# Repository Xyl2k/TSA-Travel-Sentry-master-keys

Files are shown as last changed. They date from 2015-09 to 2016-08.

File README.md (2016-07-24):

tsa

3D TSA "Travel Sentry" master keys
=========
Recently, pictures of TSA master baggage keys got leaked by the Washington Post and also [PDFs](https://www.travelsentry.org/security/pdf/passkeys.pdf) hosted on TravelSentry's Website. This repo is a [reproduction attempt](https://twitter.com/InfoSecJesus/status/641662669758574593) 

Security researchers have [long warned](http://www.crypto.com/masterkey.html) of the dangers of using [master-keyed locks](https://twitter.com/J0hnnyXm4s/status/642123709311008768)

The TSA has issued an official statement making it known that [they don't even care that we've done this](https://theintercept.com/2015/09/16/tsa-doesnt-really-care-luggage-locks-hacked/), as the now-pointless locks affect theft prevention, not airline safety. 

> **[!] Important**: These keys have not been widely-tested, though we do have reports that many [do work](https://twitter.com/bernard/status/641662069427847168) from at least [one source](http://arstechnica.com/security/2015/09/video-3d-printed-tsa-travel-sentry-keys-really-do-open-tsa-locks/). 006 May never work, as we're not sure of the depth of the "dimples," and also consumer-grade 3D printers may not be up to such finely-detailed tasks.

> Added the stubby versions of the keys by [MS3FGX](https://github.com/MS3FGX), which appear to [still work fine !](https://twitter.com/JimyLongs/status/641820527892414464)

### Thanks:
- Special thanks to [@darksim905](https://twitter.com/darksim905) and [@irongeek_adc](https://twitter.com/irongeek_adc/status/640907196197404672) and some anonymous others who all sent us images and information surrounding these keys. Also, [@j0hnnyXm4s](https://twitter.com/J0hnnyXm4s) for his key size ratios and issue management / advice.

3D TSA "Safe Skies" master key
=========
Safe Skies manufactures TSA-approved locks under their own standard, competing with Travel Sentry, and has even sued Travel Sentry for patent infringement. They have a much smaller market share than Travel Sentry. These locks can be identified by noting the words "Safe Skies" next to the keyway, in a similar location as the Travel Sentry "TSA00N" notations. All available information indicates only one override/master key exists for their entire system. Armed with this knowledge and a large hammer (no, really), [@darksim905](https://twitter.com/darksim905) and [Nite0wl](https://twitter.com/nite0wl_2600) reverse-engineered the master key bitting, and created 3D files suitable for printing. They presented their findings along with [@j0hnnyXm4s](https://twitter.com/J0hnnyXm4s) at the 11th Hackers of Planet Earth conference in New York City, in July of 2016.

PROBLEM REPORTING
=========

If you print a key and it doesn't work:
	
* First, use a caliper or other highly-accurate device to make sure the key you printed is accurate to the model. Humidity, expansion & ambient room temperature can have serious effects on print size accuracy.

* If it IS accurate, open an issue on the github, specify the problem file, and what problems exist (i.e. "Too wide for the keyway," "Too tall for the keyway," etc.).

* Upload a picture of your lock's keyway. 

* If you have the original keys for the lock, provide a measurement of the key from shoulder to tip, total height of the shoulders, and width. (i.e. X, Y & Z axes of the blade). Some keys only have one shoulder. 

LICENSE
=========
This project is released under the Creative Commons Attribution-NonCommercial 3.0 Unported License.



You are free to:

* Share — copy and redistribute the material in any medium or format
* Adapt — remix, transform, and build upon the material
* The licensor cannot revoke these freedoms as long as you follow the license terms.

Under the following terms:

* [!]Attribution — You must give appropriate credit to all contributors to this project, provide a link to the license, and indicate if changes were made. You may do so in any reasonable manner, but not in any way that suggests the licensor endorses you or your use.

* [!]NonCommercial — You may not use the material for commercial purposes.
No additional restrictions — You may not apply legal terms or technological measures that legally restrict others from doing anything the license permits.

Notices:

You do not have to comply with the license for elements of the material in the public domain or where your use is permitted by an applicable exception or limitation.

No warranties are given.

For the full text of this license, see [LICENSE.md](https://github.com/Xyl2k/TSA-Travel-Sentry-master-keys/blob/master/LICENSE.md).

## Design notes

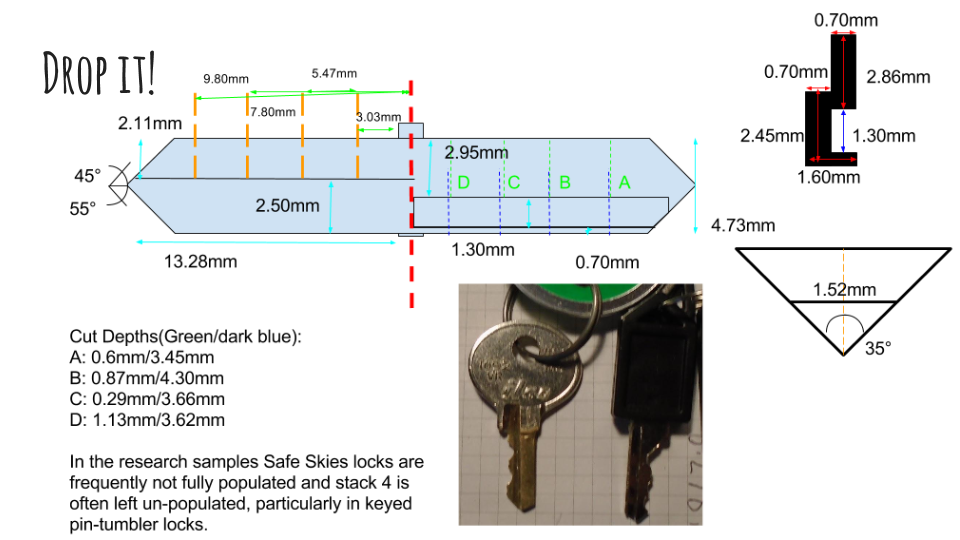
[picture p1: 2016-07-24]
Safe_Skies/Cut__depths__and__angles.png

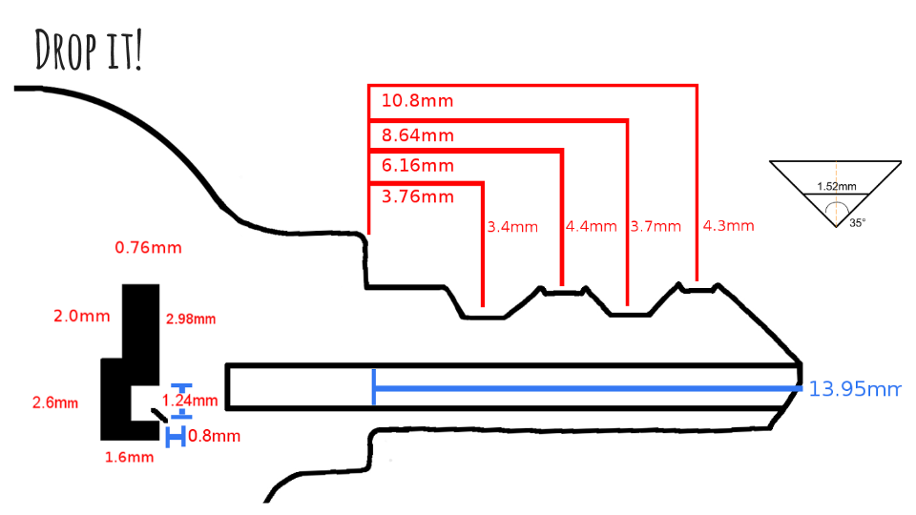
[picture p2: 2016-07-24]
Safe_Skies/Keyway__and__bitting.png

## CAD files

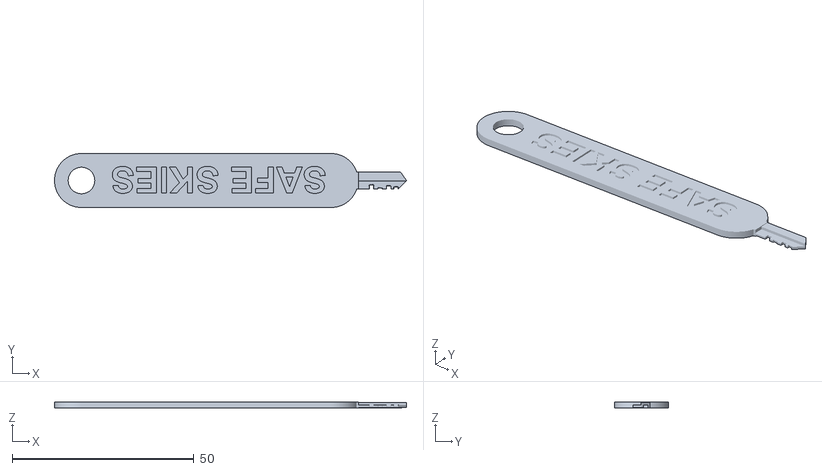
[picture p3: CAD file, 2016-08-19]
Safe_Skies/SafeSkies_full.stl
96.8 x 14.8 x 1.76

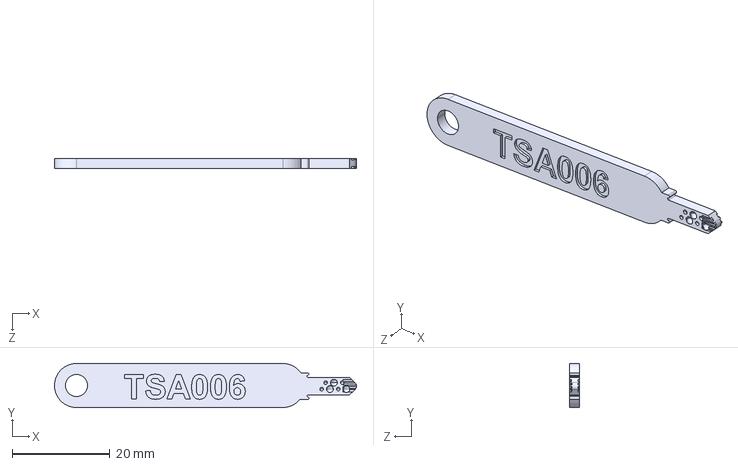
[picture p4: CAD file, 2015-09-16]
IGES/TSA006.IGS
61.7 x 9.00 x 2.00 mm

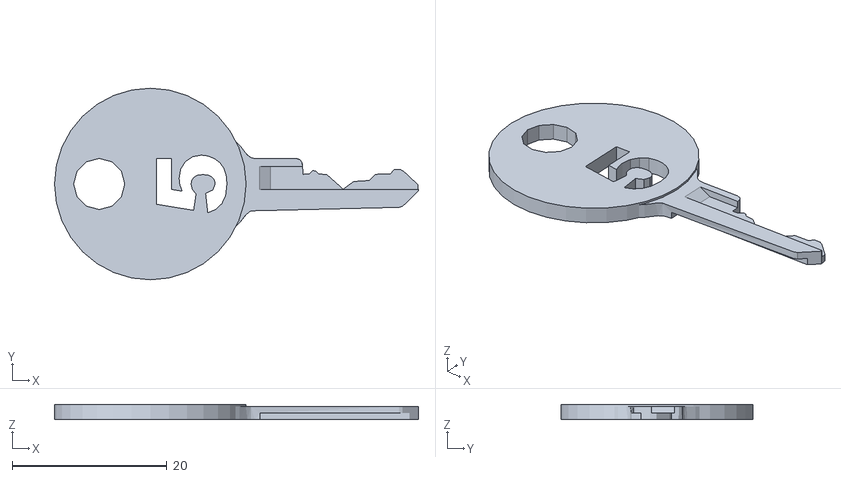
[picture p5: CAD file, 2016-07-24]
TSA005_stubby.stl
47.0 x 24.8 x 1.98

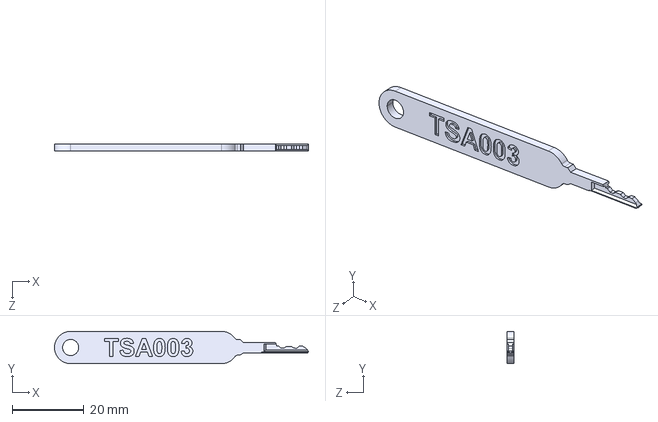
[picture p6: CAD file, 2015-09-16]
IGES/TSA003.IGS
70.9 x 9.00 x 2.00 mm

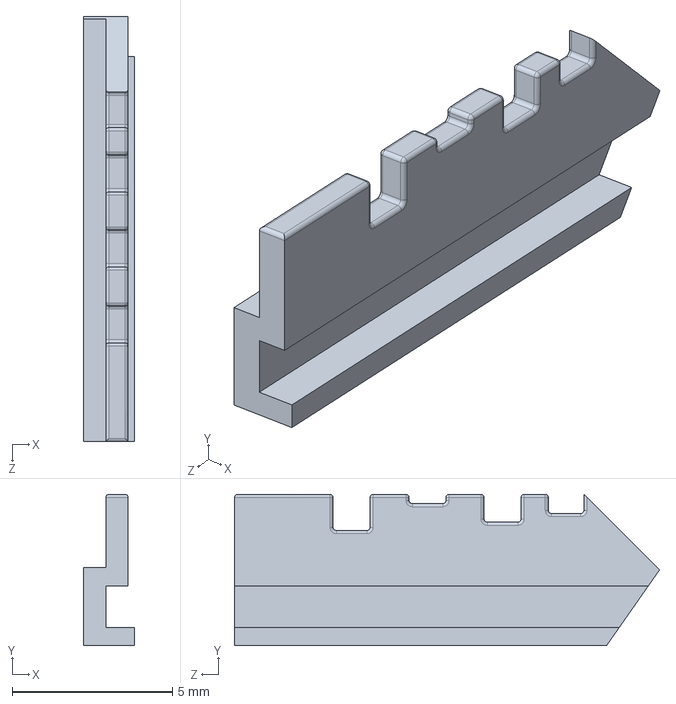
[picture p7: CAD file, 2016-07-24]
Safe_Skies/SafeSkies__FILLET__.SLDPRT
1.60 x 4.73 x 13.3 mm

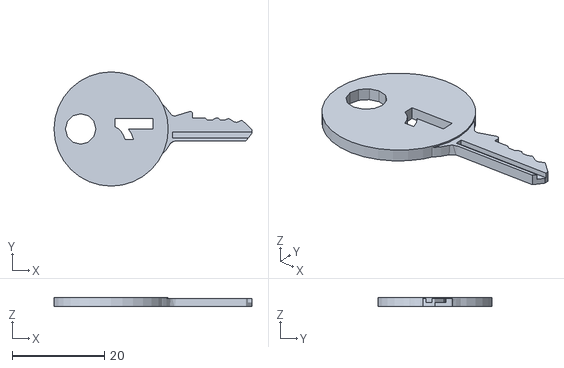
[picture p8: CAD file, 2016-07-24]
TSA001_stubby.stl
42.9 x 24.8 x 2.01

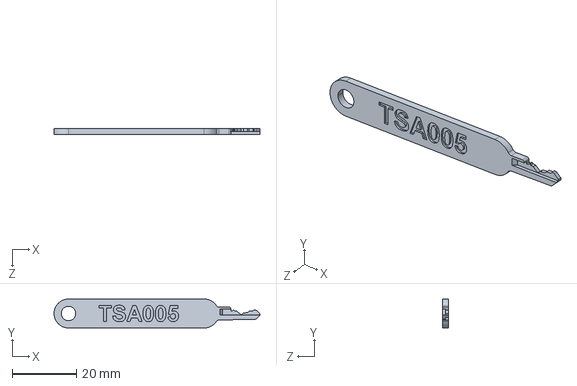
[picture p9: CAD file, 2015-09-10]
IGES/TSA005.IGS
64.0 x 9.00 x 1.75 mm

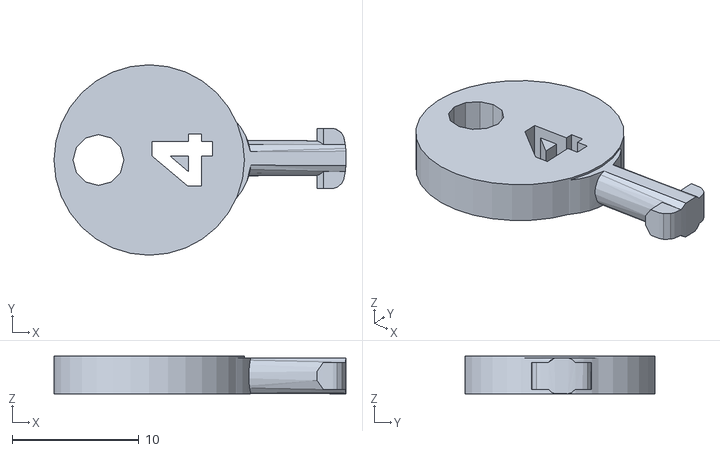
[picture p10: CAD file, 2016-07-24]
TSA004_stubby.stl
23.0 x 15.0 x 2.98

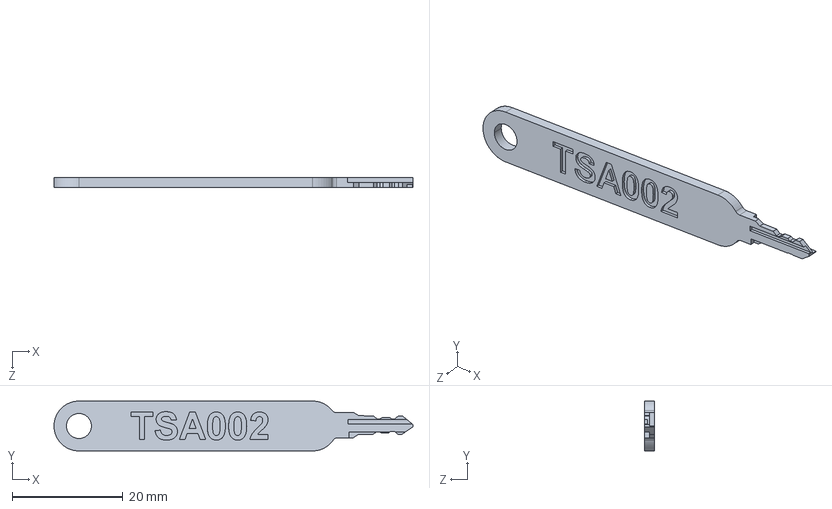
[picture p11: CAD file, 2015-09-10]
IGES/TSA002.IGS
64.7 x 9.00 x 1.75 mm

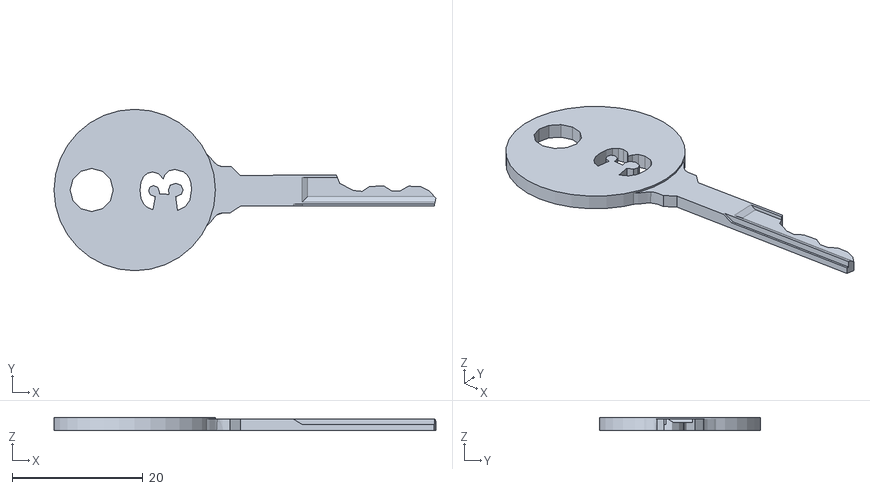
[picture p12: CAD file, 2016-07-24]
TSA003_stubby.stl
58.5 x 24.7 x 2.01

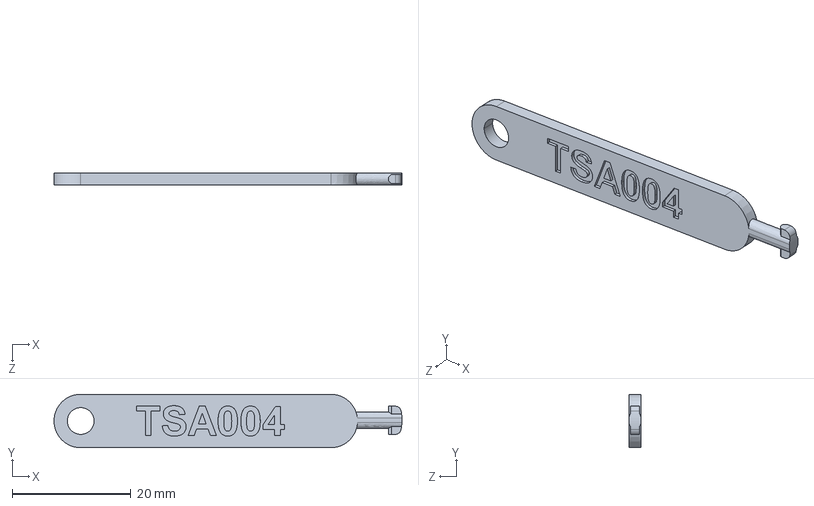
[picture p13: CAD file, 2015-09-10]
IGES/TSA004.IGS
58.6 x 9.00 x 2.00 mm

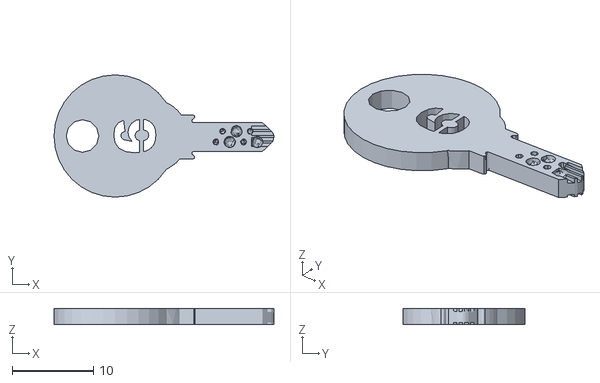
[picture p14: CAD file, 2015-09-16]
TSA006_stubby.stl
27.0 x 15.0 x 2.00

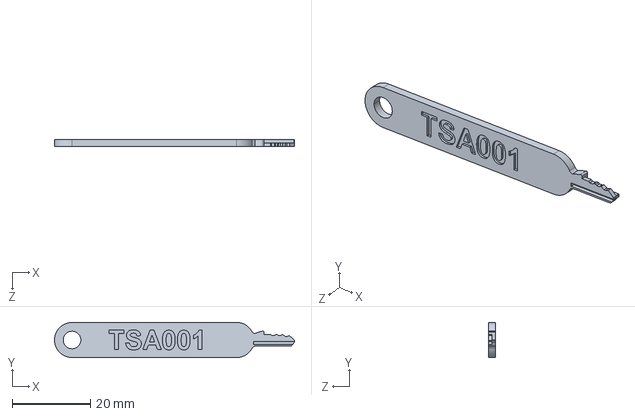
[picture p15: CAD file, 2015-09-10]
IGES/TSA001.IGS
61.5 x 9.00 x 1.75 mm

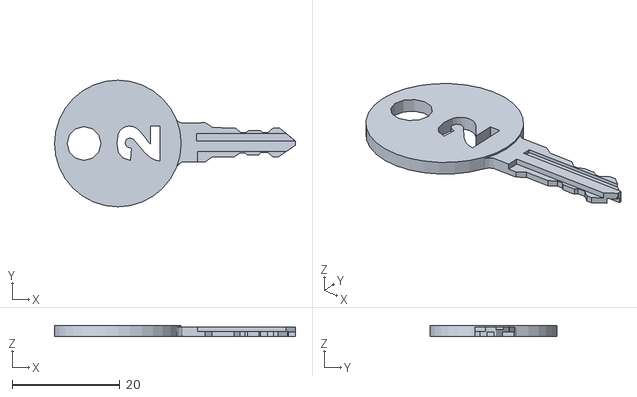
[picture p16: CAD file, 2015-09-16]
TSA002_stubby.stl
44.8 x 23.6 x 2.01

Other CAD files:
Safe_Skies/SafeSkies__no__cuts.SLDPRT
Safe_Skies/SafeSkies.SLDPRT
IGES/TSA007.IGS
TSA007_stubby.stl
Safe_Skies/SafeSkies.stl
TSA001.stl
TSA002.stl
TSA003.stl
TSA004.stl
TSA005.stl
TSA006.stl
TSA007.stl

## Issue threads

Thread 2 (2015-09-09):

Which unit was used?

hanneshal, 2015-09-09:
Which unit was used to create your stl files?
Are they in inch, mm, cm?

regards

Xyl2k, 2015-09-09:
Hi, millimeters

Date: Wed, 9 Sep 2015 10:40:37 -0700
From: notifications@github.com
To: TSA-Travel-Sentry-master-keys@noreply.github.com
Subject: [TSA-Travel-Sentry-master-keys] Which unit was used? (#2)

Which unit was used to create your stl files?

Are they in inch, mm, cm?

regards

—
Reply to this email directly or view it on GitHub.

hanneshal, 2015-09-09:
thx

Closed 2015-09-09.

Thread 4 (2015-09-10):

where's the license?

burdickjp, 2015-09-10:
May I suggest you use the CERN open hardware license?
http://www.ohwr.org/documents/294

3TroubleMonster, 2015-09-10:
Fuck u

MS3FGX, 2015-09-10:
Licensing for something like this strikes me as a bit tricky. As it stands, the files presented are duplicates of real-world objects which we don't have the rights to. Just because you make a digital representation/duplicate of an object doesn't mean you can now assert your rights as it's owner; the rightful owner is still whoever created it.

So for the existing TSA key STL files, I would think the safest approach would be a very permissive license, something like a 3 clause BSD. That would give attribution, but stop short of putting restrictions on the how and why the files can be used. My specific concern with the CERN license is the very opening of their prerequisite:

*Authorship/ownership of the design must be clear and undisputed. Only the legal owner of the rights in the hardware design may decide under what conditions to make it available.*

Looking ahead, I think it would be a good idea to create some new STL (maybe even SCAD) files for a set of keys **based** on the original TSA set. In that case, I agree a robust license like the CERN OHL would be a logical choice.

burdickjp, 2015-09-10:
That is a very, very good point. I'm still wrapping my head around hardware licenses. As you've demonstrated, they can be very tricky in comparison to software licenses.

3TroubleMonster, 2015-09-10:
Stopv

On Thu, Sep 10, 2015, 3:00 PM Jeffrey Burdick <notifications@github.com>
wrote:

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

Xyl2k, 2015-09-17:
in the U.S. keys are utilitiarian objects and as such are not eligible for copyright protection, mechanical keys and locks are instead protected by patents, but that is a non-copyright restriction.
As it's master keys, the reproduced keys in themselves may contravene patent laws -if they where offered for sale- but i think it's fine here.

From wiki: https://en.wikipedia.org/wiki/Key_blank

"keys stamped with "Do not duplicate" or "It is unlawful to duplicate this key" are, with few exceptions, perfectly legal to duplicate."

What's about the WTFPL license ?

MS3FGX, 2015-09-17:
As you say, traditional open software licensees (like the GPL) are not very good choices for hardware because they deal with the concept of copyright. Open hardware licenses, on the other hand (like CERN and TAPR) are designed with patentable objects in mind. So CERN would be an applicable license to a non-copyrightable object, but there is still the issue of who really owns the design.

We could simply release them as public domain, but I thought using a BSD license would be better as it would at least require attribution to the original project. So people would be free to do whatever they wish with the objects, as long as they said where they got them from.

WTFPL is essentially just a public domain license (since the concept of public domain doesn't exist in all countries, the WTFPL is an explicit statement of the concept), but is often avoided because it isn't a very professional statement. It's also considered redundant since there are existing licenses that do the same thing, so it has not been approved by the OSI.

For what it's worth, the FSF suggests the use of a Creative Commons license for 3D models of utilitarian objects: http://www.gnu.org/licenses/license-list.html#Designs

CC0 could be used if the goal is to put the models in the public domain.

johnnyxmas, 2015-09-17:
Totally valid. They "real" keys don't have a patent# on them, and I have to imagine if they were, the TSA would have tried a Cease & Desist by now, or sent Github a takedown. Even if they ARE patented, we're still free to do this because  I think [Creative Commons Zero](https://en.wikipedia.org/wiki/Creative_Commons_license#Zero_.2F_public_domain) is more politically-correct, but has the same sentiment:

As far as U.S. reverse-engineering laws go, it looks like we're able to RE these keys if it's for the purposes of [developing new locks that will be compliant with them](https://en.wikipedia.org/wiki/Reverse_engineering#Overlap_with_patent_law). That's just my interpretation though.

My only real concern, and this is just a personal thing, is I don't like the idea of other people making money off of something they didn't design. I release all of my stuff on Thingiverse as "Creative Commons 3.0 Attribution / Non-Commercial" meaning they must give credit to me for the design, and aren't allowed to sell anything based off it. They're able to reproduce and distribute for free, however. As the majority of each of these designs is based on your work, I'd say you get the final say on licensing.

Xyl2k, 2015-09-17:
I don't like the idea of someone selling these too, it would be totally unethical.

@johnnyxmas: since you guys also help on TSA models you have your word to say, that why i don't want to take a decision alone.
Creative Commons 3.0 Attribution / Non-Commercial seem a good choice, if you agree too (MS3FGX?) let's close this and go for CC BY-NC 3.0 ?

MS3FGX, 2015-09-17:
Like Johnny, I license my creations on Thingiverse under CC BY-NA as well. I'm fine with that license and would have no objection to that becoming what we use here.

The only question I would have is does the non-commercial aspect mean it would be more difficult to have them printed by the user?

For example, does the TOS for services like Shapeways and 3D Hubs prohibit users from printing objects with a non-commercial license?

johnnyxmas, 2015-09-17:
No, as they're selling the printing service, not the keys. If Shapeways started selling the keys themselves on their site then yes, it would prevent that (which is good). Also, I bet their ToS prevents users from even asking them to print the keys.

MS3FGX, 2015-09-17:
Good point, we're already probably in a gray area with the commercial printing outfits.

Let's go for CC BY-NC 3.0 then.

johnnyxmas, 2015-09-17:
Done. Added LICENSE.md and updated the README file to reflect it, plus some more recent information.

Closed 2015-09-17.

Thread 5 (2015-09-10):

Key Dimension are to small

morawekj, 2015-09-10:
I just print your TSA002 Key, and they are too small, TSA002 is JMA LAS2 or Silca LS13R Key Blank,
Your 14mm lenght is in original about 22mm

http://www.aldridgesecurity.co.uk/p-3699-silca-ls13r-to-suit-las.aspx

Xyl2k, 2015-09-10:
thanks for the feedback, yeah all keys are not yet good, the TSA006 is a bit tricky too as i don't know what it looks like from the other side.
If you have access to TSA002 (or any other keys) can you scan it ?
it would be the best way to get the profile of the key. It avoids parallax and lens errors from photography

johnnyxmas, 2015-09-11:
I suspect they're all too small by the same amount. See attached images for helpful dimensions for an 007 I have. Looks like 14mm from tip to shoulder, and the shoulder width is 7mm.
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

johnnyxmas, 2015-09-11:
Regarding 006, you not only need to know the placement of the dimples, but also the depth. not a massive concern, as this lock is very rare.

johnnyxmas, 2015-09-11:
CONFIRMED. An increase of X & Y of 57% while maintaining Z DOES WORK.
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

MS3FGX, 2015-09-12:
This is excellent feedback, something which is desperately needed to narrow down what does and doesn't work.

My only concern is making commits which might work perfectly for one person, and not at all for another. As it stands we have people using the existing STL files and opening locks on the first try, and then we have a case like yours where you needed to scale them up by a fairly large margin.

To me that means we either don't have a great understanding of how different people's printers/slicers are interpreting such intricate designs, or that the locks themselves are at such poor tolerances that the key only has to be vaguely correct.

In either event, I'd really like to see an effort to collect data from users as to their printing environment (hardware, slicer, filament, temps, etc) and also the make/model of the locks they are testing against before we start throwing out changes to see what sticks.

It's entirely possible that there won't be a single file that prints properly on all printers and opens all locks. But we should at least try and get as close as possible.

johnnyxmas, 2015-09-12:
I won't replace the original files; just upload my mods. Working on new STLs right now. AFAIK, we only have a single user who opened a single lock with the original print. Let's not forget that we're dealing with a lot of garbage locks that can be opened pretty easily with a rake / screwdriver / etc.

exibar, 2015-09-12:
I have a 002 lock here tat I've been trying to scale up during slicing to no avail.  I've also tried different slice widths... from .05 to .3 without success.  I'm using PLA at 185 degrees.

johnnyxmas, 2015-09-12:
Are you using my recommended ratios above?

Xyl2k, 2015-09-12:
What MS3FGX said.
slicing and 3d printer config is also a vector, i'm gonna buy a couples of TSA locks on ebay and try to see what's going on.
As some people got some keys to work without scaling, it would be probably better to fork a own repo or just renaming to avoid overwriting the original files (unless we are positive and don't need them anymore)

johnnyxmas, 2015-09-12:
I have a fork. Finishing up the full-sized STLs. Stand by.

johnnyxmas, 2015-09-12:
Pull request submitted. Have a look, LMK. I understand the size issue is controversial, so I moved everything to separate directories.

MS3FGX, 2015-09-12:
Printing 007 and 002 now.

johnnyxmas, 2015-09-12:
Since we're crowdsourcing testers, here's some suggested text for the readme. This is how I got the 007 ratios correct:

### WE NEED TESTERS \ REAL KEY SIZES!
- If you have a TSA-approved lock and key, and the master key does not work, open an "Issue" and provide the following measurements of your lock's key:
	* Blade length from shoulder to tip
	* Shoulder height from top to bottom

Xyl2k, 2015-09-14:
what's do you think of this form ?
https://docs.google.com/forms/d/1IhyyOiXtnCX5xOOxgDMyarj06O6NzQP8H_6wbRZQrFQ/viewform?c=0&w=1

johnnyxmas, 2015-09-14:
Great start! However, we need to petition feedback from people who say their keys did not work. Since we're almost definitely dealing exclusively with a sizing issue (i.e. not a bitting or key type issue), then getting an accurate measurement of the key that came with their lock is most helpful. I only need a measurement from tip-to-shoulder, and shoulder height:

https://schlagelocks.files.wordpress.com/2009/01/schlage-lock-diagram4.jpg

MS3FGX, 2015-09-14:
I agree, this is a good idea, but it isn't asking the questions we need answered.

The biggest question to me is how some people are having success with the original, and others with the enlarged version. I would be very interested in seeing a form that asked:

A. What file you used
B. What printer/slicer you used
C. What are the dimensions of the **printed** key

If we can ascertain what results people are getting in the real world with these files on their individual setups, we could make much more informed moves going forward.

My best theory right now is that some people's printers are incorrectly calibrated and printing the keys too large. That would explain why the original files worked for some people, but when they printed the 157% files the keys ended up too large.

jimklo, 2015-09-14:
I think the simple solution to this is having documented target dimensions.
We all know that we can't control everyone's calibration, and most of that
is handled per printer. So the easiest approach is to document overall
target sizes; height, width, and thickness; to the nearest 0.01mm. The STL
needs to be the normal, not some combo of printer & STL. Technically all
this is available from the STL - but often the lazy need help with this.

This way when you print version 1 of the key and version 2 - you know what
size they should measure before testing in a lock. Otherwise if the printed
version is smaller/larger than the STL size, any bug/success is more or
less invalid.

A list of good filament materials for printing keys might also be good to
maintain. My guess is PETG and ABS would be good candidates, but ABS
shrinkage might be difficult to test with. But I think printer/filament
specific tips that are relevant to printing keys should be in the GH wiki,
not in the repo.
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

Xyl2k, 2015-09-14:
I got some datas per mails but don't know if it's accurate for the moment
001 = 0.1cm
003 = 0.2cm
004 = 0.35cm
005 = 0.15cm
006 = 0.2cm
007 = 0.1cm

i'm gonna update 003 and 006 soon (someone sent me scanned pictures front and back of his keys) as i was missing some part it would be definitely better, although i'm not gonna do it right now. (I'm concentrating on other work at the moment, but this should be quick.)

johnnyxmas, 2015-09-14:
I still submit that 006 is pointless without having front and back pics of the master.

What are these measurements you posted? Z height? If so, I can confirm 007 is about .75mm too thin.

johnnyxmas, 2015-09-15:
Now [THIS] is interesting (https://twitter.com/bernard/status/641662069427847168)

This lock is WAY smaller than the 007's I have here. The Xyl2x master key is clearly properly-sized for it. This is a big can of worms, but explains the divide. Are there multiple sizes of TSA master keys in the wild?!

Xyl2k, 2015-09-15:
for 003 and 006 a little birdy sent me scanned picture of them.
i've not yet pulled them but if you want to have a look: http://temari.fr/tsa_revision_v2.rar
even if tsa006 is 'hard' to print at least this one is more accurate i think.

johnnyxmas, 2015-09-15:
Here is a scan of non-master keys from IronGeek for 002, 004, 005 & 007 (top to bottom). Good at least for showing proper scale:

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

johnnyxmas, 2015-09-18:
NOTE: I updated the info above. These are confirmed-functional hand-made master keys.

johnnyxmas, 2015-09-19:
My enlarged 002 & 003 keys work well enough that Ars Technica made
this demo of them. If we assume these two are
good, then we must increase the size of the remaining keys to be
compliant with the visual size ratios between them in the “leaked”
photos. This update implements that change (luckily it seems it was still the 157% scale across the board). Several comparisons have been made between the tested and untested keys to make sure various features “line up,” however these have STILL NOT BEEN TESTED. The
attempt here is to at least get close to fixing something that was definitely wrong.

I submitted a pull request for these, but I want you two to review it and merge it if you agree.

Closed 2018-08-23.

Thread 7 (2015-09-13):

Repo layout suggestion

jimklo, 2015-09-13:
I've been following this repo, wondering if it makes sense to use a Git-Flow style of repo branches to support merging and testing. I'm thinking out loud here, but think some organization is needed. I've done a lot of Github based OSS development, but never on an STL files so I think the problem is slightly different. If anyone has an alternative, please suggest in this issue - and maybe the maintainer will consider.

For those not familiar with Git-Flow, info here: http://nvie.com/posts/a-successful-git-branching-model/

Heres what I'm thinking:
- Master: contains full stable releases of all keys
- Develop: contains unstable releases of all keys
- Release/[key number]: contains stable version of specific keys for testing
- Feature/[key number]: contains unstable development versions of specific keys

Pull requests should happen on Feature/[key number] branches from which these would be alpha versions. Once there is some confidence of stability - merge with develop to make it beta.  Then as we think the keys are ready for release candidates, merge into release/[key number].  Once enough feedback has been submitted, the release keys can be merged and tagged on master.

Also STL's should be just STL's - for specific printing guidance for specific printers, I'd say use the Wiki features to document how to print a set.

johnnyxmas, 2015-09-13:
My thoughts:

That looks incredibly confusing, and borders on demotivating. I also think it's a bit much when you're dealing with something that has a binary outcome: either it does or does not work. If it does not work, you can open an issue and state the problem. When we think we have a solution, we can just correct for it and update the STL, where users can repeat the cycle if necessary. This is a very, very small project. Just like Steven thought having multiple directories was too much, this looks to be even more confusing.

As for printing tips, that is way outside of the scope of this project. 3D Printers are so individually unique and highly effected by environmental and material factors that the wiki would end up being full of every possible tweak and situation, rendering it pointless. This would be akin to providing someone with plans for a steering wheel for their car, and then having to give them tips on how to steer their specific car every time road conditions change. The steering wheel doesn't need to be changed to correct for these situations, so it's not our problem as the designer of steering wheels to address that. If they need to be taught how to drive in the rain in a 1997 Audi A4, they're on their own to get that sorted out. If they need to figure out how to print these STLs on their homemade printer on a humid, windy day outdoors, that's their problem, not the STLs.

MS3FGX, 2015-09-13:
That level of granularity might not be necessary for something like this, but I do agree there should be a process in place for staging modifications that are under review. Many people are getting many different results, and until it is sorted out what does and does not work for the majority, making changes is just being overly rash.

Closed 2018-08-23.

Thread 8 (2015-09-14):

Please make suggestions for what materials are suitable

kristovatlas, 2015-09-14:
I've tried contacting some local printers, and haven't been able to find one nearby who is confident that their printer will:
a) Achieve the desired resolution to print function key teeth
b) Use a material compatible with use as a key. Some materials will be too soft or brittle.

If folks could post printers/materials that have worked so far, that would be greatly appreciated. This info could be merged into the README.

MS3FGX, 2015-09-14:
First, I'd be very cautious about spending money on getting the keys printed right now. They are in a state of flux, and best case we can only say that two of them *probably* work (but even there we have some debate).

That said, I think the printers were being overly cautious. Even low end printers should be able to replicate these designs, at least for most of the keys. The people who've tested them so far have largely been using consumer-level machines. If they can't print these designs, I would wonder why business they have offering printing services to begin with.

As for material, well, there's a reason you don't usually see plastic keys...

I wouldn't recommend a printed key for long term use, but it will certainly work for awhile. Certainly long enough to experiment with. Unless you plan on using them daily, I don't see that it will be a problem. If you're worried about them wearing out, just get more made.

ssa3512, 2015-09-14:
I would expect that standard ABS or PLA would be sufficient for these locks, as they require a very small amount of torque to actually turn the cylinder.

johnnyxmas, 2015-09-14:
I feel like this isn't a bug regarding the files., and shouldn't be discussed here. Perhaps a 3D printing forum or Thingiverse or something.

kristovatlas, 2015-09-14:
I guess you could call it a feature request: Provide additional information about what materials these files have been printed on and used successfully.

johnnyxmas, 2015-09-14:
A)  MS3FGX is correct. Do not have these "professionally" made in any way unless you're doing it strictly for novelty; several of them definitely do not work, especially 006.

B) The ones I was able to test work great printed in PLA at a .01 layer height, which means ABS would work even better, which subsequently means there is no issue with these files as far as FEASIBILITY of printing goes. That means any trouble you're having is in regards to your printer setup, and NOT the source files, thus this is not a discussion suited for this repo.

What you're asking is not a feature request. All feature & bug requests / issues mean modification of the original files needs to be done. If what you’re asking does not involve having to change the files, then it is not a discussion for Github.

Sorry to be blunt, but these keys are getting global publicity, attracting tons of people, and we need to keep the repo as clean as possible. Thus, we need to eliminate scope creep at all costs. If there is not a problem SPECIFICALLY WITH THE FILES IN THIS REPO, please do not open up such requests.

Closed 2015-09-15.

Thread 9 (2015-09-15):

002 Appears to need a groove on the other side

johnnyxmas, 2015-09-15:
[Per this tweet] (https://twitter.com/RevitFur/status/643612939379830784)

This is congruent with the way I would expect the lock to be laid out.

johnnyxmas, 2015-09-15:
0.75mm wide x 0.75mm deep with a 0.5mm ridge between the original cutout

exibar, 2015-09-15:
002 for sure needs a groove on both sides...

johnnyxmas, 2015-09-15:
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

johnnyxmas, 2015-09-15:
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

MS3FGX, 2015-09-15:
I've been working on TSA002 a bit, and have come up with some improvements.

On my printer it works reliably, at least one side. I think I might be having some overhang issues on the other side, but I can't be sure. Hopefully some others can print it and see what kind of results they get. I'll make a PR for it soon.

LarryFarry, 2015-09-22:
The TSA002 worked. I also made a copy at a keymaker
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

johnnyxmas, 2015-09-22:
Excellent. If we can get a couple more confirmations, we can close this.

Xyl2k, 2015-09-22:
very nice

Xyl2k, 2015-09-23:
Received my tsa002, from latest MS3FGX update:

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

johnnyxmas, 2015-09-23:
Looks solid. I’m willing to call this issue closed if you are. 

Xyl2k, 2015-09-23:
i think it's good yep

MS3FGX, 2015-09-23:
Awesome, looks like another one down.

Closed 2015-09-23.

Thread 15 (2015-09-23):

007 is Too Thick

johnnyxmas, 2015-09-23:
While you can certainly cram it in there with some fiddling at the current 2.0mm, the actual key width for 007 is 1.6mm.

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

johnnyxmas, 2015-09-23:
I've had great success with my two 007 locks using the new thinner 007 key in my fork. Submitted a pull request for now, but waiting for more testers.

https://github.com/johnnyxmas/TSA-Travel-Sentry-master-keys/blob/master/TSA007_stubby.stl

MS3FGX, 2015-09-23:
Your key's are coming out at 2 mm? The STL specifies 1.75, and when they come off my printer I am measuring ~1.71 mm on my calipers.

Maybe you're running into some kind of layer height problem? Are you using .3 mm layers perhaps?

Xyl2k, 2015-09-23:
The actual TSA007 file from the main branch work absolutely fine here.

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

johnnyxmas, 2015-09-23:
I just pulled the file off this repo and confirmed in 2 different programs. 2.01mm:

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

johnnyxmas, 2015-09-23:
1.75 should have enough room to work, but 2.0 definitely doesn't easily fit in my locks. They're completely different from Xyl2k's; his are combination locks, mine are not. 2.0mm is standard for Schlage or Kwikset-style "house" keys, so I'd believe if some of these keys need to be that width, but the keys for my 007 are definitely thinner, measuring ~1.6mm.  Perhaps there's a slight difference in the keyway width between the two. A slightly thinner key should work on both, but the thicker one would not.

I can try them at 1.75 later today and if that works in my lock, I'd say at least replace the current 2.0's with that.

MS3FGX, 2015-09-23:
Well yeah, the entire key itself is 2 mm high, but that's because the "handle" is thicker than the actual key. At least on my stubby ones anyway, the original keys are the same thickness throughout.

If you pull the regular TSA007, you should see it reads as 1.75 mm.

johnnyxmas, 2015-09-23:
Confirmed; good call; I confirmed this at the shoulder. Either way, the 1.75's take a lot of struggling to get into these locks. Once you get it in a few times and wear \ compress the plastic down, the key does work.  Can you try my 1.6's in the combination-style lock and see if they still work? If so, this may be a better master key. If it's too thin to the point where it's difficult to use there, we may need to either declare my old locks "obsolete,"  create a "7b" key for them,  or just make a note that the keyways on some of them are a bit thinner and require some force (probably the easiest option). I'd have been willing to write it off as poor lock production tolerances, but I've got 2 of them here.  :/

Xyl2k, 2015-09-23:
Your version worked too but seem very fragile due to the tickness

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

MS3FGX, 2015-09-23:
That would be my concern, surely the thinner one would work on both locks, but why make the default smaller and weaker?

This might be something where we have a note in the docs that says some makes/models/types/whatever of locks need Z scalled down slightly.

johnnyxmas, 2015-09-23:
I'm OK with that. I was thinking of adding some basic / universal printing tips to the README per some conversations with darksim, anyway. This is certainly something that could potentially apply to all keys.

Closed 2015-09-23.

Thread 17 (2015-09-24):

Tried on actual Luggage?

Gnagha, 2015-09-24:
Did anyone of you ever tried to use the keys on actual luggage locks? I made a 007-Key and it works well with a padlock, but it didn't with a suitcase lock. Any ideas?

MS3FGX, 2015-09-24:
You mean a TSA lock integrated into a piece of luggage rather than being external? Now that you mention it, no, I haven't seen anyone test with that. Probably because we all just went out and bought some cheap TSA locks to start testing/working with. Personally, I don't even own any luggage, and haven't been on a plane in 20+ years.

Anyway, why doesn't it work? Does it not fit, or does it not turn?

Gnagha, 2015-09-24:
I don't really know, why it didn't work.

I went to a shop this morning and tried it on actual luggage. While my external locks work fine with these keys, these integrated locks didnt open. After quiet a while the 002 key worked, but it was quiet difficult. Much jiggling was needed and a lot of strenght. The 007 key didn't work at all while it works like an original key on the external locks.

The keys fit in, but I wasn't able to turn. I was frightened to break them.

johnnyxmas, 2015-09-24:
The following may be helpful:

*Dimensions in mm of the key blade for the stock key. If you have a caliper handy, using this would be excellent. At the very least, a picture of the key next to a metric ruler.

*Picture of the stock key next to the printed one

*Confirmation that the key you printed is within .1mm of the original file. Again, caliper.

iandotmartin, 2015-09-29:
I can confirm the TSA 002 opened the lock successfully after some initial difficulty. I should be able to post measurements/pictures in the next few days.

Gnagha, 2015-09-30:
Can you post the measurements? I wanted to print some keys later again. So I could try them.

Closed 2018-08-23.

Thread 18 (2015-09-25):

Collection of working keys

Gnagha, 2015-09-25:
Can someone reup or relink all working keys again in the right dimension? I'm a bit confused by all these files. A link would be very helpful because I want to print the keys with a metacrylate photopolymer gum and don't have a CAD programm right now.

I want to try a better printer and better material, maybe then the keys work on more locks.

Thanks, G.

MS3FGX, 2015-09-25:
The files in the repository are already the best working ones, as far as anyone knows. Most have not been tested, however, so there's no guarantee.

Only 002, 003, and 007 are known to work (and even then, it seems to depend on lock type/manufacturer).

Gnagha, 2015-09-25:
Okay .. then I'm going to print those in a better quality. I let you know if they work on different locks.

MS3FGX, 2015-09-25:
What locks do you have access to? Any testing that can be done on the 4 remaining keys would be very helpful.

Gnagha, 2015-09-25:
The shops I went to only have 007 and 002 :/

johnnyxmas, 2015-09-25:
I'm at DerbyCon with IronGeek. We've got all 7 locks here. Will sit down and test sometime this weekend.

Gnagha, 2015-09-30:
How did it work?

johnnyxmas, 2015-09-30:
I was able to print working keys for 2,3,5 & 7. I also obtained measurements for 004, and believe I have a good file now.  The files I used are in my repo; I don't want to submit a pull request to merge them here until more people test. Please feel free to do so:

https://github.com/johnnyxmas/TSA-Travel-Sentry-master-keys

amckenna, 2015-10-02:
I have access to 1, 2, 4, 7 locks. I used the files from this repo and used shapeways.com to print them (figured it would be higher quality then borrowing someone extrusion printer).

001 - key fit but didn't turn
002 - key fit but didn't turn
004 - key did not fit
007 - key fit and it turned

I've included a picture of key 4 next to the lock.

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

johnnyxmas, 2015-10-02:
See my comment above.

amckenna, 2015-10-02:
Yup I saw it, I'm just confirming that the ones in this repo are not good except 7.

MS3FGX, 2015-10-02:
Well, not good for _your_ locks. You are the first to report problems for 002 since the new version, as far as I'm aware.

elyajizi, 2021-04-26:
Hello , coming back here since it has been a life saving for me , got 2 big cases bought from Japan with 002 (TSA E150 and 734)  . Lost all keys and had only a dirty reproduction that worked hardly made by locksmith . I just last week found out that thisproject exist , and used your 092 file sent to a Chinese company that printed it on stainless steel  , working like a charms on 3 différents cases . Some polishing will be required since the print finish in stainless steel make key a bit hard to push on the lock , but definitely work 100%
Cheers

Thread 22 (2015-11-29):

Rimowa tsa006 too small

macst34, 2015-11-29:
My wife doesn't know how to operate her luggage and decided to spin the number wheels and set a new code.

I printed out the current stl on my prusa using PLA and also on a DLP resin printer.

I found that the key was too small.

I know my wife is going to pull the same stunt again, so I am committed to drafting a working key.

I believe if I scale the current key, it should have a good change of opening the lock.

Enclosed are rudimentary pictures of the keyway.

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

-m

MS3FGX, 2015-11-29:
Interesting to get a lead on the elusive 006, but honestly can't do much with these pictures. We really need the numbers from a decent set of calipers to do anything with accuracy.

Since I'm guessing that's not something you have access to, it would probably be more effective if you can take a closeup of the printed key lined up with the opening, that way we could at least make an estimate visually on what the difference is.

Off the top of your head, how much bigger do you think it needs to be? A lot, a little?

macst34, 2015-11-30:
Hiya MS3FGX,

The initial pictures are just because my cell phone and tape measure are what I had on hand.
I do have some manual calipers at the lab and I will get some measurements for you. The external keyway should be easy to measure, though depth is probably more difficult to determine because of the gate pattern at the bottom of the key that I am assuming is reflected in the lock.

In any case, the luggage boarded a plane for trip to halfway around the world. It and my spouse are coming back in about 2 weeks.

To answer your question: Just eyeballing it dimensions of the keyway, it seems to be ~2mm(x) and ~6.5mm(y):
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

The printed key was too thin in the x dimension by ~0.4mm and too short in the y dimension by ~2mm, so I am guessing a scale up of ~30% is needed.

Interesting thing from peering inside the keyway and actuating the pins a bit , it seems there are only pins on the top row of the lock. This means only top part of the key is needed. I don't know if all TSA006 keyways are like this or if the lock that I got was just a cost down model. It does make sense since using the top of the key should engage 4 pins on the "left" side and 3 pins on the "right" side. This would be 7 pins for this lock instead of 14 pins if all the dimples on the key were populated. A 14 pin lock might be a little overkill for a luggage level theft deterrent.

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
(Only the green dimples on both sides are used.)

take it easy,

-m

johnnyxmas, 2015-11-30:
This is good info. If you can get some precise measurements, I can push a beta key to my repo here:

https://github.com/johnnyxmas/TSA-Travel-Sentry-master-keys/blob/master/TSA006_stubby.stl

The 006 I have in there now seems like the width might be correct, but not the height. You're welcome to print it out and try.

More interesting is the row of pins. If what you say is true (I understand it's just speculation), I'd look into adding the rows of 4 dimples on each side of the top of the key, at the very least making a potential rake out of it.

macst34, 2015-12-02:
Hi Johnnyxmas,

As I said before, the luggage is still traveling and will be back in a little while. I'll be able to give better measurements of the keyway then. I did print out the xyl2k_stubby_006 stl and my comments above reflect my initial experiences with it.

Your stubby006 stl fork seems to be the same exact dimensions as xyl3k's. So without scaling up a bit there's no real reason to print and test yours also.

The pin layout is not so much speculation, as much as a cursory inspection. I could not identify any pins for the lower half of the keyway. As such, a minimized bump key should only need 7 dimples, but can only be inserted one way. If you are going to go though the trouble of making a bump key, why not just do all 14 dimples so it can be symmetrical? Then you could use it by feel when you have to bump luggage locks on the dark... :)

But why make a bump key at all? TSA locks of the same type should never be keyed differently. i.e. when you have a TSA key, you have the key to open all TSA locks of the same type. Bumping need not apply.

I'll come back with some numbers or a solution when the wife gets back.

-m

johnnyxmas, 2015-12-03:
Sorry, Q3 & Q4 are nuts in my profession, so I haven't been in the repos in a few months. I'll get back to it soon as a few of us are putting a panel together for the Hope conference in NYC next summer.
I was talking about raking, not a bump key. I can't imagine even ABS keys would hold up well for bumping. I imagine

macst34, 2015-12-05:
Heya Johnnyxmas,

Hope your job lets up soon. after all, the holidays are almost upon us.

Raking is still along the same lines...why rake if we already have pin placement and depth?  A rake (or alternatively, a bump key) would only be useful if the locks are keyed differently. As we know, all the locks for a particular key type are keyed the same. So I am not sure when you expect to run into a case where you have the same keyway but not the same pins.

The tolerances on the Rimowa lock seem more than adequate for a luggage level theft deterrent. If you didn't know the dimple depths, I think it might be not all that easy to rake...though I haven't tried.

-m

johnnyxmas, 2018-08-21:
So Nite0wl dumped some 006 locks and we're pretty sure there's only 2 actual pin depths for the dimples, and the diameters likely don't matter, probably because only one bit is used to drill both (dimple gets wider as the beveled bit drills deeper).

Unfortunately this is the limit of what my self-taught CAD skills can handle, especially with only STL files to work with. I've attached Nite0wl's measurements here, for anyone who wants to try their hand.
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

johnnyxmas, 2018-08-23:
FYI new versions of 006 have been uploaded to my testing repo here: https://github.com/johnnyxmas/TSA-Travel-Sentry-master-keys

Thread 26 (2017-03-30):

key no.2

Mannmaan, 2017-03-30:

Mannmaan, 2017-03-30:
Recently the stupid TSA "unlock" my luggage in Orlando and did not turn to "Lock" position after they check  my Tumi Luggage that happen to have TSA0002 key on the locking system.
so in my search for the key, i came across this article and did 3D printed TSA0002 with the file provided.
but im facing a problem, the key doesn't even fit in the insert. please advise or can someone send other link.
thanks

MS3FGX, 2017-03-30:
The 2 key is generally known to work, so there's a good chance the issue is in the printer calibration.

Is the key too wide, or too thick? If it's too thick I'd start by trying to sand the top side down a bit untill it fits. If it's too wide, you should measure it with calipers to see how far off it is compared to the target dimensions.

You can also try scaling down the problem dimension in your slicer. For example if the keys are coming out too thick, you might try setting the Z scale to .98 - .95.

Mannmaan, 2017-03-30:
thanks for your advise, it appear to be too wide. i will try to scale down.

johnnyxmas, 2017-03-30:
Yes, the manufacturing tolerances of locks have been found to be surprisingly lenient, so a need to adjust the width of printed keys is to be expected on occasion. Also be aware the plastic expands & contracts due to environmental effects, so it may take several tries and some tweaking to get a key that works.

Thanks,

JohnnyXmas | @j0hnnyxm4s
~~*\Sent while mobile/*~~

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

Mannmaan, 2017-03-30:
Thanks Johnnyxmas. plastic expedition due to environmental make a lot of sense since i live in Jakarta Indonesia. it very very hot and high humidity down here.

Closed 2018-08-23.

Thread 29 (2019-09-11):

TSA_004_stubby.stl

MisterGlass, 2019-09-11:
PrusaSlicer is showing numerous errors in the TSA 004 stuby STL file. It seems like netfab is able to repair it easily.

**
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
**

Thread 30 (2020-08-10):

TSA002 slightly inaccurate? TSA006 too small

kouwei32, 2020-08-10:
I have just recently tested TSA002 on 2 locks. Curiously, it worked _once_ on the first lock - unlocking it easily - but hasn't worked again (the key goes in but doesn't turn in the other direction). It only went halfway into the second lock. Seems like there's a bit of inaccuracy on the model, but I'm not sure if it is really the model or the print that is broken.

TSA006 was also way too small (but mentioned already in #22). I'm currently also printing an updated one from johnnyxmas's repo for a test later.

I can provide pictures and measurements later if necessary, since I'm a bit busy right now.

johnnyxmas, 2020-08-11:
Please watch this explanation of tolerances (or lack thereof) with these locks AND the inherent flaws in 3D printing to begin with: [https://youtu.be/GekBT0a3STQ?t=2042](https://youtu.be/GekBT0a3STQ?t=2042)

scuty2000, 2020-12-25:
On my lock I think the TSA002 is too long, the core is very short. I'll send images tomorrow.

vvasuki, 2021-11-24:
tsa2 mismatch images

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

anthony1204, 2024-12-04:
tsa 2 nearly got stuck in one of my new luggages.

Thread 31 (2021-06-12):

Print settings

Lud-T, 2021-06-12:
Hello,

What are the best print settings ?

Which type of support ?

Thank you.

johnnyxmas, 2021-08-09:
 This is not information we can provide to as per the reasons listed in the readme. They are too specific to your exact printer, filament, print head and environmental factors so this is unfortunately something you must experiment with on your own (the same as printing anything else).

Thank You,
Johnny Xmas
Security Advocate || CISSP - GIAC - GPEN

PGP / Keybase: https://keybase.io/j0hnnyxm4s
Youtube: https://tinyurl.com/87ft7vpf
Twitter: @J0hnnyXm4s
Insecure Phone: (410)H4X-0R3D
Secure Phone: By Request

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

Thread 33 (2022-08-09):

Scaling issue?

carlni2008, 2022-08-09:
IDK but these doen't seems to be right for me.
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

johnnyxmas, 2022-08-09:
Can you provide detailed information? These have been tested by quite a few people.

carlni2008, 2022-08-09:
> Can you provide detailed information? These have been tested by quite a few people.

So downloaded all the files one by one and dragged them into my printer's software. But the sizes seems weird to me, because i think they should all be in the same size. I checked the scalling on my software, they are all in a hundred percent.

knowthebird, 2023-09-22:
Very new to 3d printing here, but I also see the same scaling issue when I download the zip of the repo and open these in the Prusa slicer. By default TSA002 measures 101 mm for me. The photo above is very similar (the same in think) to what I see.

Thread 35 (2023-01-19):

What printer head is recommended?

vincentcox, 2023-01-19:
Because of the fine size of the keys, what size of the printer head is recommended? And which printing material to avoid getting the smaller printer head clogged

MS3FGX, 2023-01-19:
I assume you mean nozzle. Personally I did everything with standard 0.4 mm nozzle in PLA.

A smaller nozzle is always nice for greater detail, but at least for the major keys (2/7), the details aren't particularly fine to begin with. That, plus the locks themselves are sloppy enough that you really only need to get close.

johnnyxmas, 2023-01-19:
I wouldn't recommend using FDM printers at all for this minute work, though it's been confirmed to be possible. Use the finest possible head and layer height your printer supports, and apply a whole lot of hope. I'd recommend SLA or SLS printers instead due to their resistance to environmental variables and increased resolutions.

Overall, this is outside of the scope of this project. The files here are an accurate recreation of the real keys, but accurately recreating them on an FDM printer has so many variables outside of the files' control that we can't do anything about it here. Please only open issues that relate to the accuracy of the files.

Closed 2023-01-19.

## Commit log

2015-09-09 Initial commit
    Initial commit
    [TSA001.stl, TSA002.stl, TSA003.stl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]
2015-09-09 Fix mistype
    Fixed a typo mistake 'TDA' instead of 'TSA'
    [TSA006.stl]
2015-09-09 Stubby versions of 7 and 2
    [TSA002_stubby.stl, TSA007_stubby.stl]
2015-09-09 Complete stubby versions
    [TSA001_stubby.stl, TSA003_stubby.stl, TSA004_stubby.stl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]
2015-09-09 Fix clipping
    [TSA001_stubby.stl]
2015-09-10 Initial commit
    Added IGS files as requested to try making these keys out of metal
    (aluminum and maybe steel)
    [TSA001.IGS, TSA002.IGS, TSA003.IGS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]
2015-09-10 Applied physics
    [TSA006_stubby.stl]
2015-09-13 Enlarged 157%, courtesy JohnnyXmas
    [TSA007.stl, TSA007_stubby.stl]
2015-09-15 Revert "Enlarged 157%, courtesy JohnnyXmas"
    This reverts commit 6d617bc18bd6bc1c548f36ff89fcb9f123fa47e9.
    [TSA007.stl, TSA007_stubby.stl]
2015-09-15 Enlarged, added grove on back
    [TSA002.stl, TSA002_stubby.stl]
2015-09-16 Fixed a face
    Fixed a face of TSA003 and TSA006 who was flat.
    A face of the key was missing, but someone sent me a new front+back scan
    of both keys to correct that.
    [TSA003.IGS, TSA003.stl, TSA006.IGS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]
2015-09-16 Stubby versions updated for 3/6
    [TSA003_stubby.stl, TSA006_stubby.stl]
2015-09-17 Key 003 scaled to proper dimensions
    [TSA003.stl, TSA003_stubby.stl]
2015-09-23 Adjusted Key Width
    Adjusted key width to 1.6mm, down from 2.0mm to be compliant with key
    widths from known 007 locks.
    [TSA007.stl, TSA007_stubby.stl]
2015-09-27 Revert "Adjusted Key Width"
    This reverts commit f94e925047be28c8c500a2e32f4faacdbd381e97.
    [TSA007.stl, TSA007_stubby.stl]
2015-09-27 Increased Height of 004's
    While the width of the stock 004’s “wings” did match the real key, the
    height of the rod did not. Increased height to 3.0mm to match the real
    key.
    [TSA004.stl, TSA004_stubby.stl]
2015-09-27 Increased 005's X & Y by 165%
    Increased 005's X & Y by 165% to properly fit in lock. Tested in 2
    locks.
    [TSA005.stl, TSA005_stubby.stl]
2015-09-28 Increased X&Y by 165%
    Increased X&Y by 165% to match visual ratio vs the 005 keys. NOT
    TESTED.
    [TSA001.stl, TSA001_stubby.stl]
2015-09-28 Increased size slightly
    Increased size to match non-master 003 key dimensions. Tested
    functional!
    [TSA003.stl, TSA003_stubby.stl]
2016-07-24 Added Safe Skies Master Key
    Added files & information presented at Hackers of Planet Earth XI for
    the Safe Skies Master Key
    [SafeSkies.SLDPRT, SafeSkies.stl, SafeSkies__FILLET__.SLDPRT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]
2016-08-19 Added Safe Skies master key with full size handle
    [SafeSkies_full.stl]
